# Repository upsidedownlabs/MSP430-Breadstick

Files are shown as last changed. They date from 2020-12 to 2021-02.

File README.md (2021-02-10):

# MSP430 Breadstick

 

Upside Down Labs MSP430 Breadstick is a development board for ultra low power MSP430G2553 MCU from Texas Instruments. 

## Variant: Cheese Dip
Cheese Dip variant of MSP430 Breadstick comes with CH340C USB to UART bridge.

| Front |  Back |
| :---: | :---: |
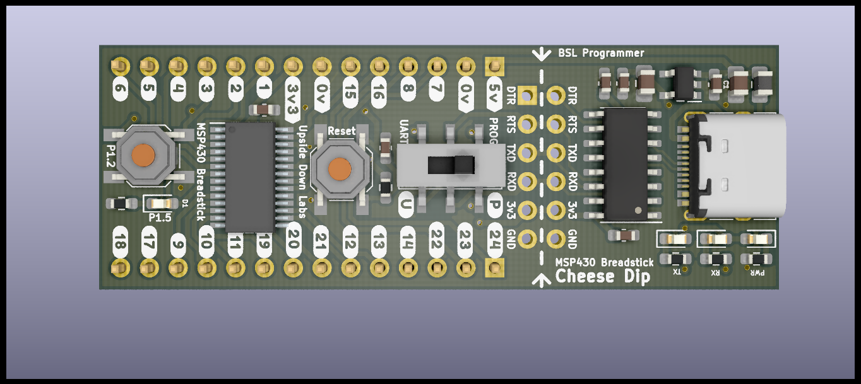
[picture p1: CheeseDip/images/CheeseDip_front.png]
Upside Down Labs MSP430 Breadstick front
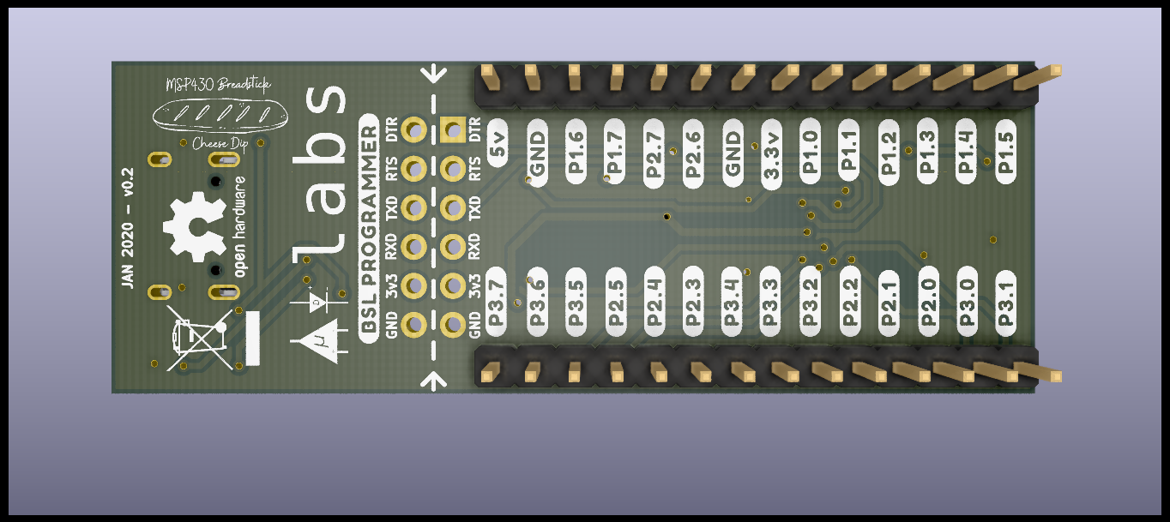
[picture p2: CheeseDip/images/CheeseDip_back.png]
Upside Down Labs MSP430 Breadstick back
|   |  |

|Pinout|
| :--: |
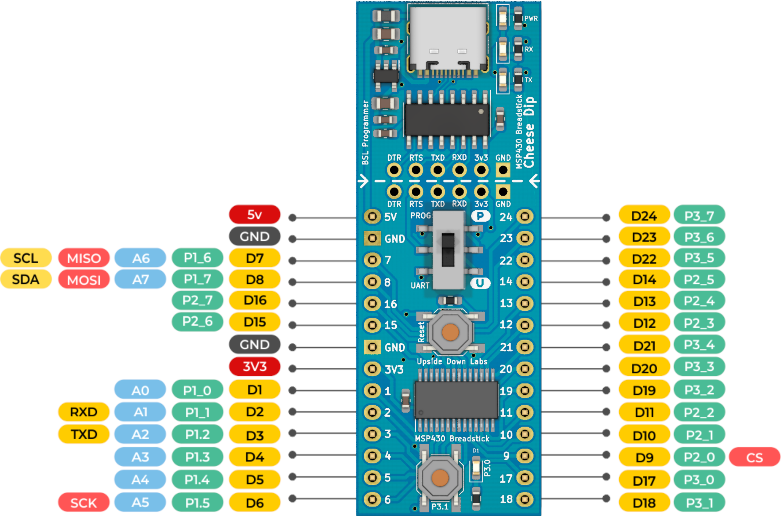
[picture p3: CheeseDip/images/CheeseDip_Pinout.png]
||

| Dimensions |  Schematic |
| :---: | :---: |
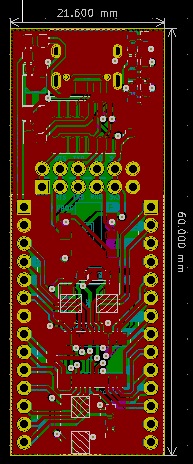
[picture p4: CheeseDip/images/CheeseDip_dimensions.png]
Upside Down Labs MSP430 Breadstick dimensions
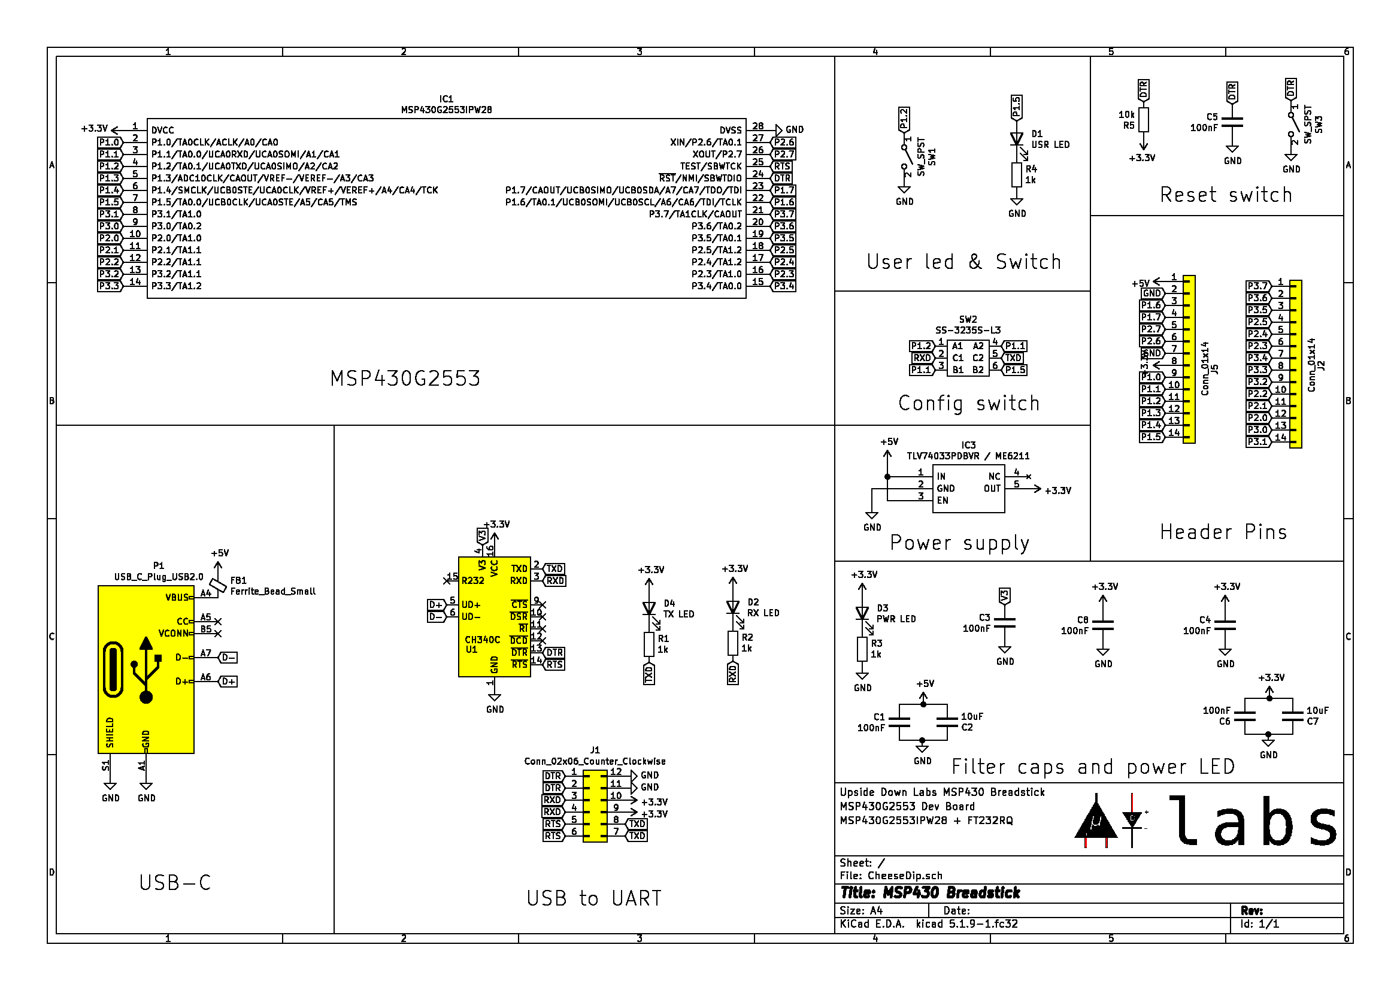
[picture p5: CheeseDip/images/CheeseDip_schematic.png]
Upside Down Labs MSP430 Breadstick schematic
| 60.00 x 21.60 mm  |  |

## Variant: Apple Sauce
Apple Sauce variant of MSP430 Breadstick comes with FT232RQ USB to UART bridge.

| Front |  Back |
| :---: | :---: |
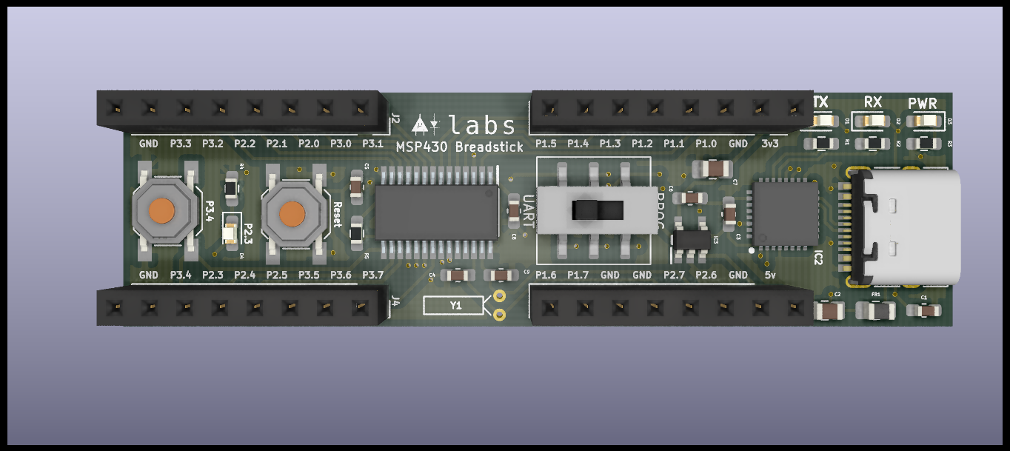
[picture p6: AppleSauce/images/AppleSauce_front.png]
Upside Down Labs MSP430 Breadstick front
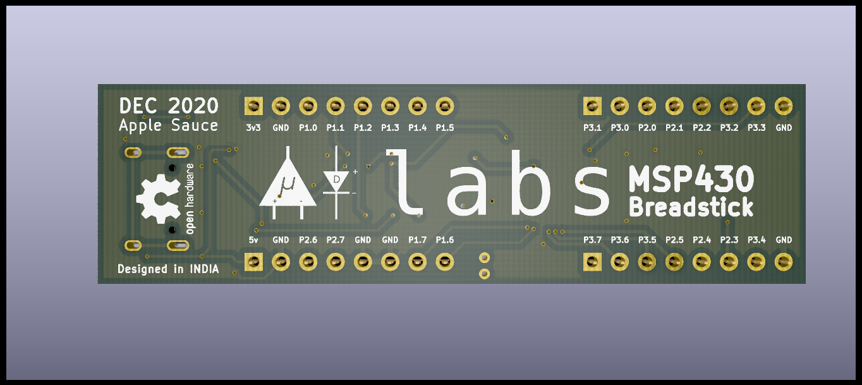
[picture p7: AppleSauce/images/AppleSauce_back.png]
Upside Down Labs MSP430 Breadstick back
|   |  |

| Dimensions |  Schematic |
| :---: | :---: |
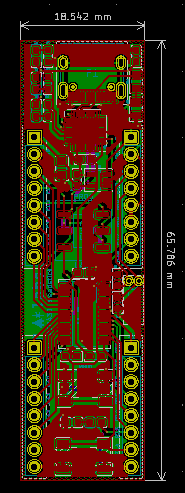
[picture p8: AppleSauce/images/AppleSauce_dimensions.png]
Upside Down Labs MSP430 Breadstick dimensions
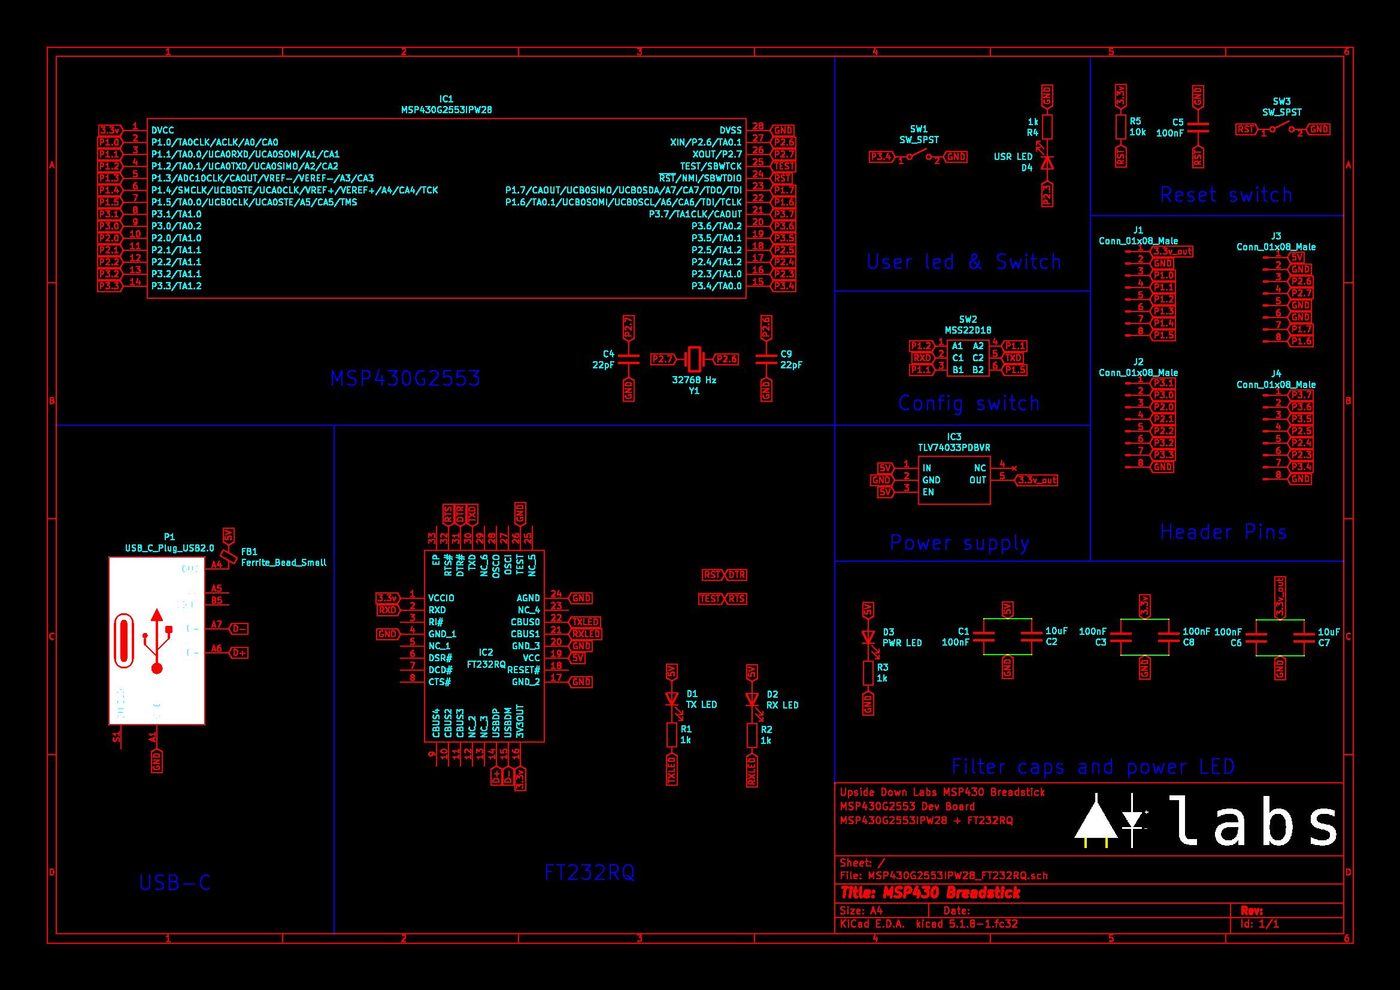
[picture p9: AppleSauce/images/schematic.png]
Upside Down Labs MSP430 Breadstick schematic
| 65.786 x 18.542 mm  |  |

## License

#### Hardware
CERN Open Hardware License Version 2 - Strongly Reciprocal ([CERN-OHL-S-2.0](https://spdx.org/licenses/CERN-OHL-S-2.0.html)).

#### Software
MIT open source [license](http://opensource.org/licenses/MIT).

#### Documentation:
<br />This work is licensed under a <a rel="license" href="http://creativecommons.org/licenses/by/4.0/">Creative Commons Attribution 4.0 International License</a>.

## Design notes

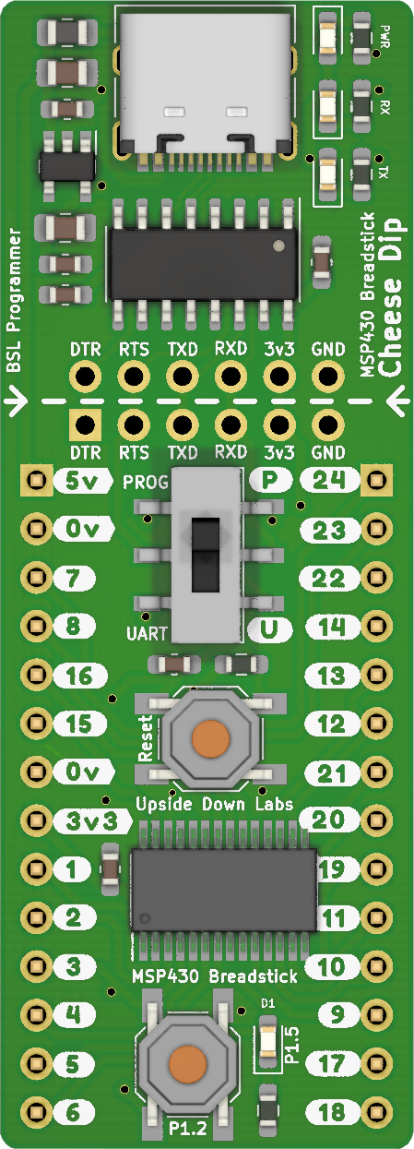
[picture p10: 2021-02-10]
CheeseDip/images/CheeseDip_Dark_Green.png

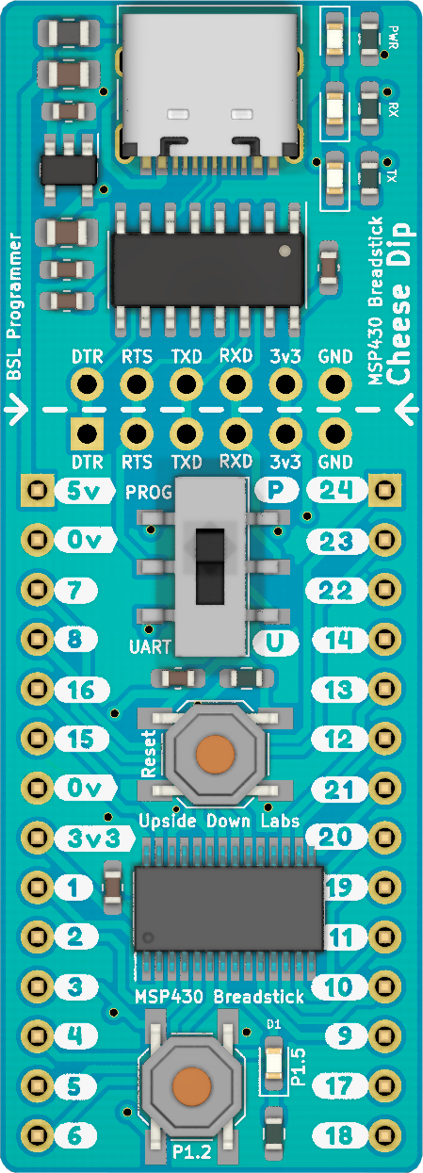
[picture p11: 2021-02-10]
CheeseDip/images/CheeseDip_SeaBlue.png

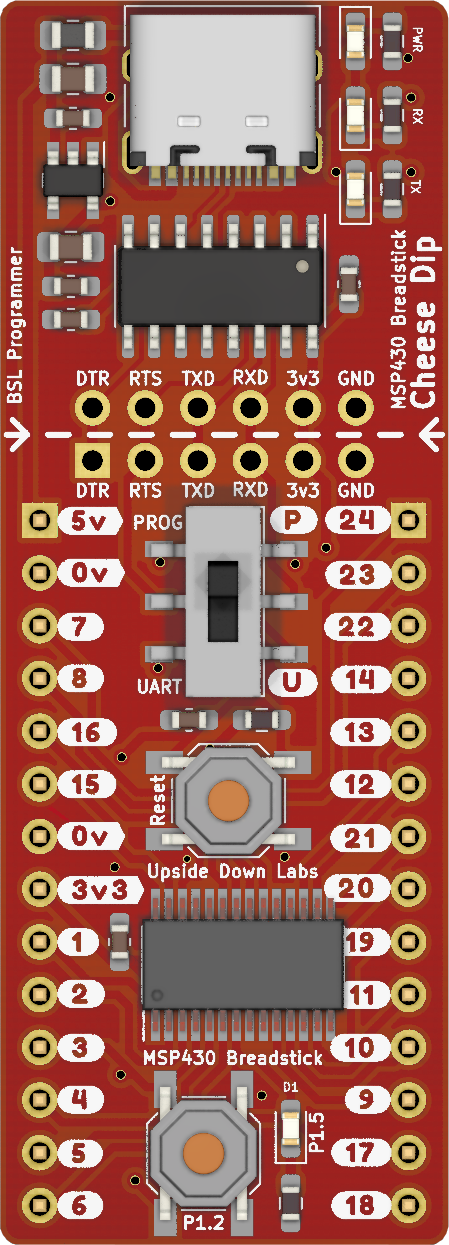
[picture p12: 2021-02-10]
CheeseDip/images/CheeseDip_Brown.png

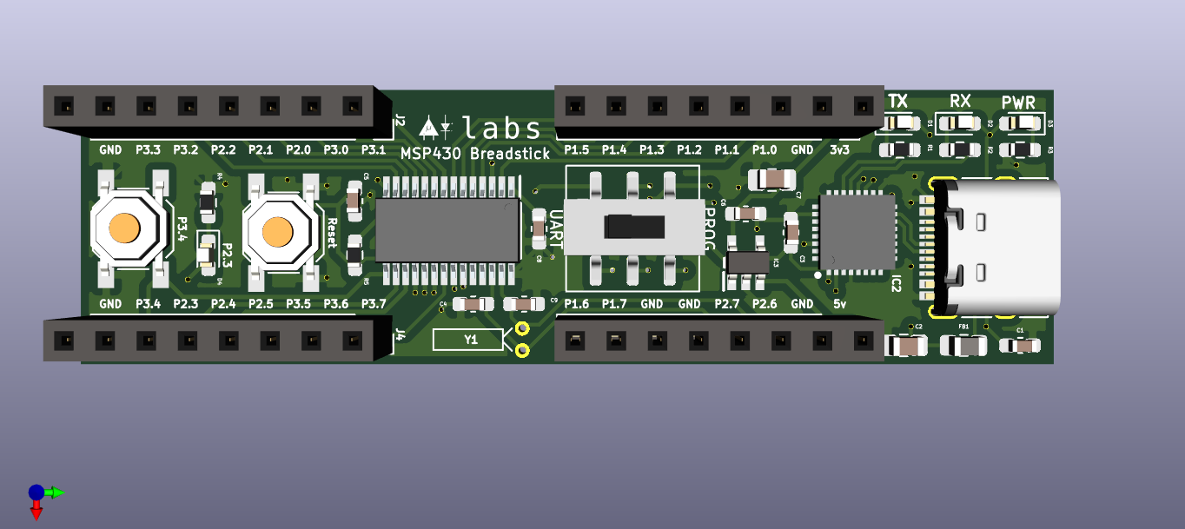
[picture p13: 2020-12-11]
AppleSauce/images/NRT_AppleSauce_front.png

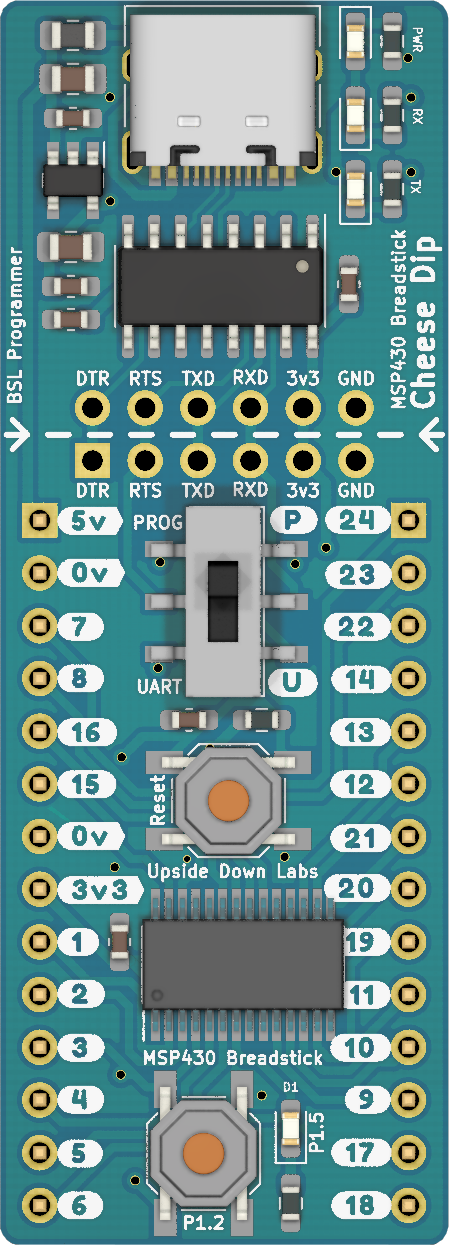
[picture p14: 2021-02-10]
CheeseDip/images/CheeseDip_Deep_Blue.png

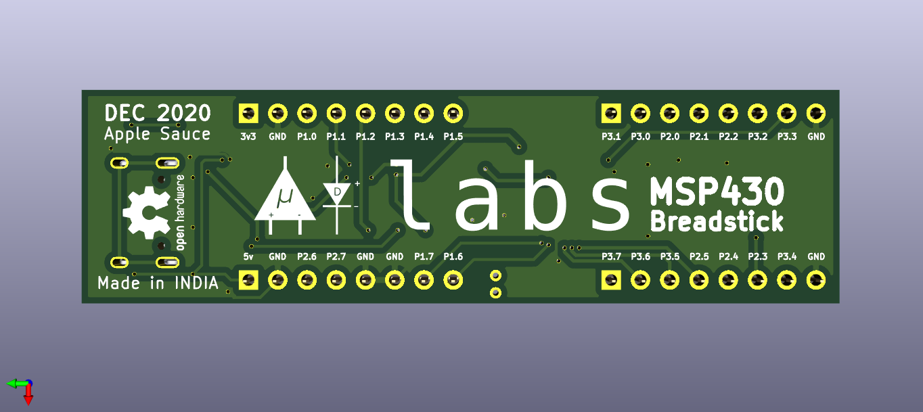
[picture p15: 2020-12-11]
AppleSauce/images/NRT_AppleSauce_back.png

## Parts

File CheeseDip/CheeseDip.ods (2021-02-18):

Ref | Qnty | Value | Cmp name | Footprint | Description | Vendor | LCSC
C1, C3, C4, C5, C6, C8, | 6 | 100nF | C | Capacitor_SMD:C_0603_1608Metric_Pad1.08x0.95mm_HandSolder | Unpolarized capacitor
C2, C7, | 2 | 10uF | C | Capacitor_SMD:C_0805_2012Metric_Pad1.18x1.45mm_HandSolder | Unpolarized capacitor
D1, | 1 | USR LED | LED | LED_SMD:LED_0603_1608Metric_Pad1.05x0.95mm_HandSolder | Light emitting diode
D2, | 1 | RX LED | LED | LED_SMD:LED_0603_1608Metric_Pad1.05x0.95mm_HandSolder | Light emitting diode
D3, | 1 | PWR LED | LED | LED_SMD:LED_0603_1608Metric_Pad1.05x0.95mm_HandSolder | Light emitting diode
D4, | 1 | TX LED | LED | LED_SMD:LED_0603_1608Metric_Pad1.05x0.95mm_HandSolder | Light emitting diode
FB1, | 1 | Ferrite_Bead_Small | Ferrite_Bead_Small | Inductor_SMD:L_0805_2012Metric_Pad1.15x1.40mm_HandSolder | Ferrite bead, small symbol
IC1, | 1 | MSP430G2553IPW28 | MSP430G2553IPW28 | udlabs:MSP430G2553IPW28 | Mixed Signal MCU MSP430 16K Flash TSSOP Texas Instruments MSP430G2553IPW28, 16bit MSP430 Microcontroller, 16MHz, 16 kB Flash, 28-Pin TSSOP | Texas Instruments | C13622
IC3, | 1 | ME6211 | ME6211 | udlabs:ME6211 | LDO Voltage Regulators |  | C82942
P1, | 1 | USB_C_Plug_USB2.0 | USB_C_Plug_USB2.0 | Connector_USB:USB_C_Receptacle_HRO_TYPE-C-31-M-12 | USB 2.0-only Type-C Plug connector |  | C720629
R1, R2, R3, R4, | 4 | 1k | R | Resistor_SMD:R_0603_1608Metric_Pad0.98x0.95mm_HandSolder | Resistor
R5, | 1 | 10k | R | Resistor_SMD:R_0603_1608Metric_Pad0.98x0.95mm_HandSolder | Resistor
SW1, SW3, | 2 | SW_SPST | SW_SPST | Button_Switch_SMD:SW_SPST_SKQG_WithStem | Single Pole Single Throw (SPST) switch |  | C318884
SW2, | 1 | SS-3235S-L3 | SS-3235S-L3 | udlabs:SS-3235S-L3 |  |  | C381098
U1, | 1 | CH340C | CH340C | Package_SO:SOIC-16_3.9x9.9mm_P1.27mm | USB serial converter, UART, SOIC-16 |  | C84681
Component Count: | 28

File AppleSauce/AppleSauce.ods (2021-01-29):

Source: | MSP430_Breadstick/MSP430G2553IPW28_FT232RQ/MSP430G2553IPW28_FT232RQ.sch
Date: | Wed 13 Jan 2021 12:40:15 PM IST
Tool: | Eeschema 5.1.9-1.fc32
Generator: | /usr/share/kicad/plugins/bom_csv_grouped_by_value_with_fp.py
Component Count: | 31
Ref | Qnty | Value | Cmp name | Footprint | Description | Vendor
C1, C3, C5, C6, C8, | 5 | 100nF | C | Capacitor_SMD:C_0603_1608Metric_Pad1.08x0.95mm_HandSolder | Unpolarized capacitor
C2, C7, | 2 | 10uF | C | Capacitor_SMD:C_0805_2012Metric_Pad1.18x1.45mm_HandSolder | Unpolarized capacitor
C4, C9, | 2 | 22pF | C | Capacitor_SMD:C_0603_1608Metric_Pad1.08x0.95mm_HandSolder | Unpolarized capacitor
D1, | 1 | TX LED | LED | LED_SMD:LED_0603_1608Metric_Pad1.05x0.95mm_HandSolder | Light emitting diode
D2, | 1 | RX LED | LED | LED_SMD:LED_0603_1608Metric_Pad1.05x0.95mm_HandSolder | Light emitting diode
D3, | 1 | PWR LED | LED | LED_SMD:LED_0603_1608Metric_Pad1.05x0.95mm_HandSolder | Light emitting diode
D4, | 1 | USR LED | LED | LED_SMD:LED_0603_1608Metric_Pad1.05x0.95mm_HandSolder | Light emitting diode
FB1, | 1 | Ferrite_Bead_Small | Ferrite_Bead_Small | Inductor_SMD:L_0805_2012Metric_Pad1.15x1.40mm_HandSolder | Ferrite bead, small symbol
IC1, | 1 | MSP430G2553IPW28 | MSP430G2553IPW28 | udlabs:MSP430G2553IPW28 | Mixed Signal MCU MSP430 16K Flash TSSOP Texas Instruments MSP430G2553IPW28, 16bit MSP430 Microcontroller, 16MHz, 16 kB Flash, 28-Pin TSSOP
IC2, | 1 | FT232RQ | FT232RQ | udlabs:FT232RQ | USB Interface IC USB to Serial UART Enhanced IC QFN-32
IC3, | 1 | TLV74033PDBVR | TLV74033PDBVR | udlabs:TLV74033PDBVR | LDO Voltage Regulators
J1, J2, J3, J4, | 4 | Conn_01x08_Male | Conn_01x08_Male | Connector_PinSocket_2.54mm:PinSocket_1x08_P2.54mm_Vertical | Generic connector, single row, 01x08, script generated (kicad-library-utils/schlib/autogen/connector/)
P1, | 1 | USB_C_Plug_USB2.0 | USB_C_Plug_USB2.0 | Connector_USB:USB_C_Receptacle_HRO_TYPE-C-31-M-12 | USB 2.0-only Type-C Plug connector
R1, R2, R3, R4, | 4 | 1k | R | Resistor_SMD:R_0603_1608Metric_Pad0.98x0.95mm_HandSolder | Resistor
R5, | 1 | 10k | R | Resistor_SMD:R_0603_1608Metric_Pad0.98x0.95mm_HandSolder | Resistor
SW1, SW3, | 2 | SW_SPST | SW_SPST | Button_Switch_SMD:SW_SPST_SKQG_WithStem | Single Pole Single Throw (SPST) switch
SW2, | 1 | MSS22D18 | MSS22D18 | udlabs:MSS22D18
Y1, | 1 | 32768 Hz | Crystal | Crystal:Crystal_DS10_D1.0mm_L4.3mm_Horizontal | Two pin crystal

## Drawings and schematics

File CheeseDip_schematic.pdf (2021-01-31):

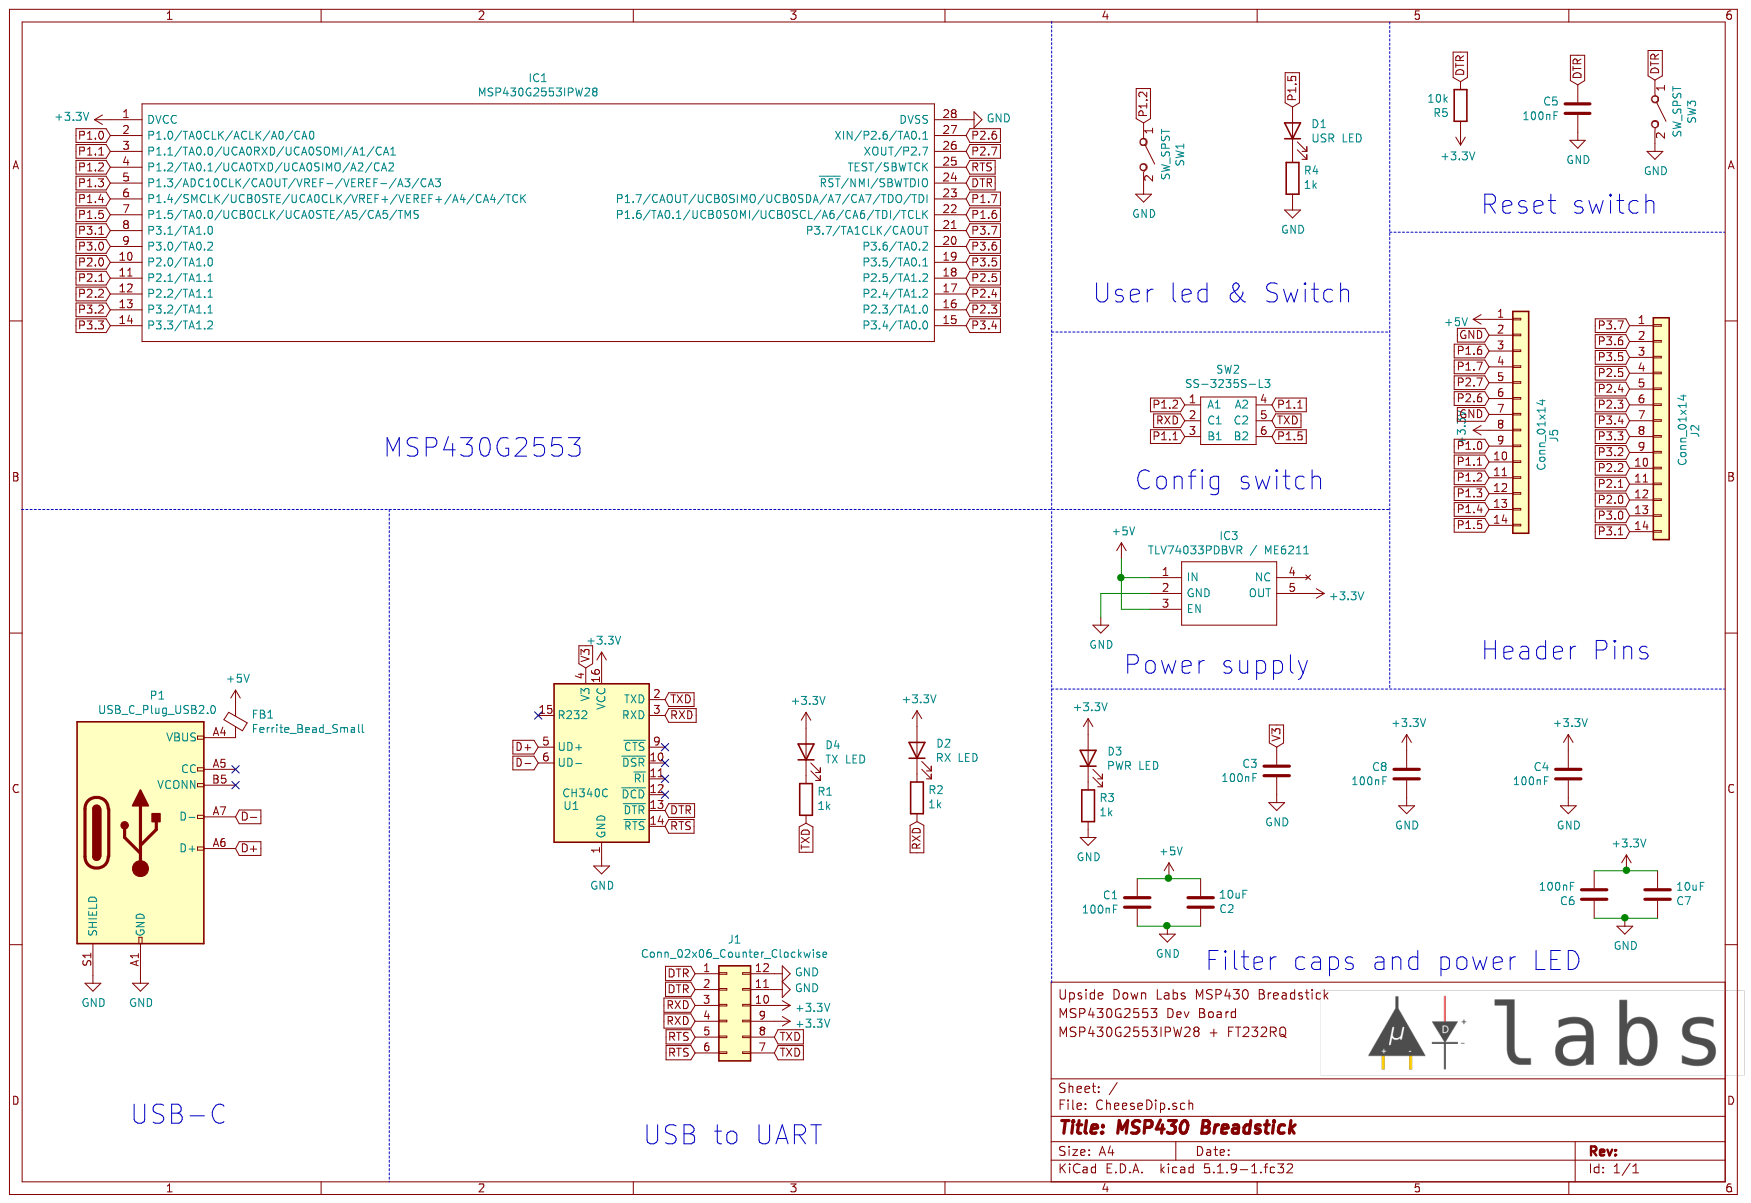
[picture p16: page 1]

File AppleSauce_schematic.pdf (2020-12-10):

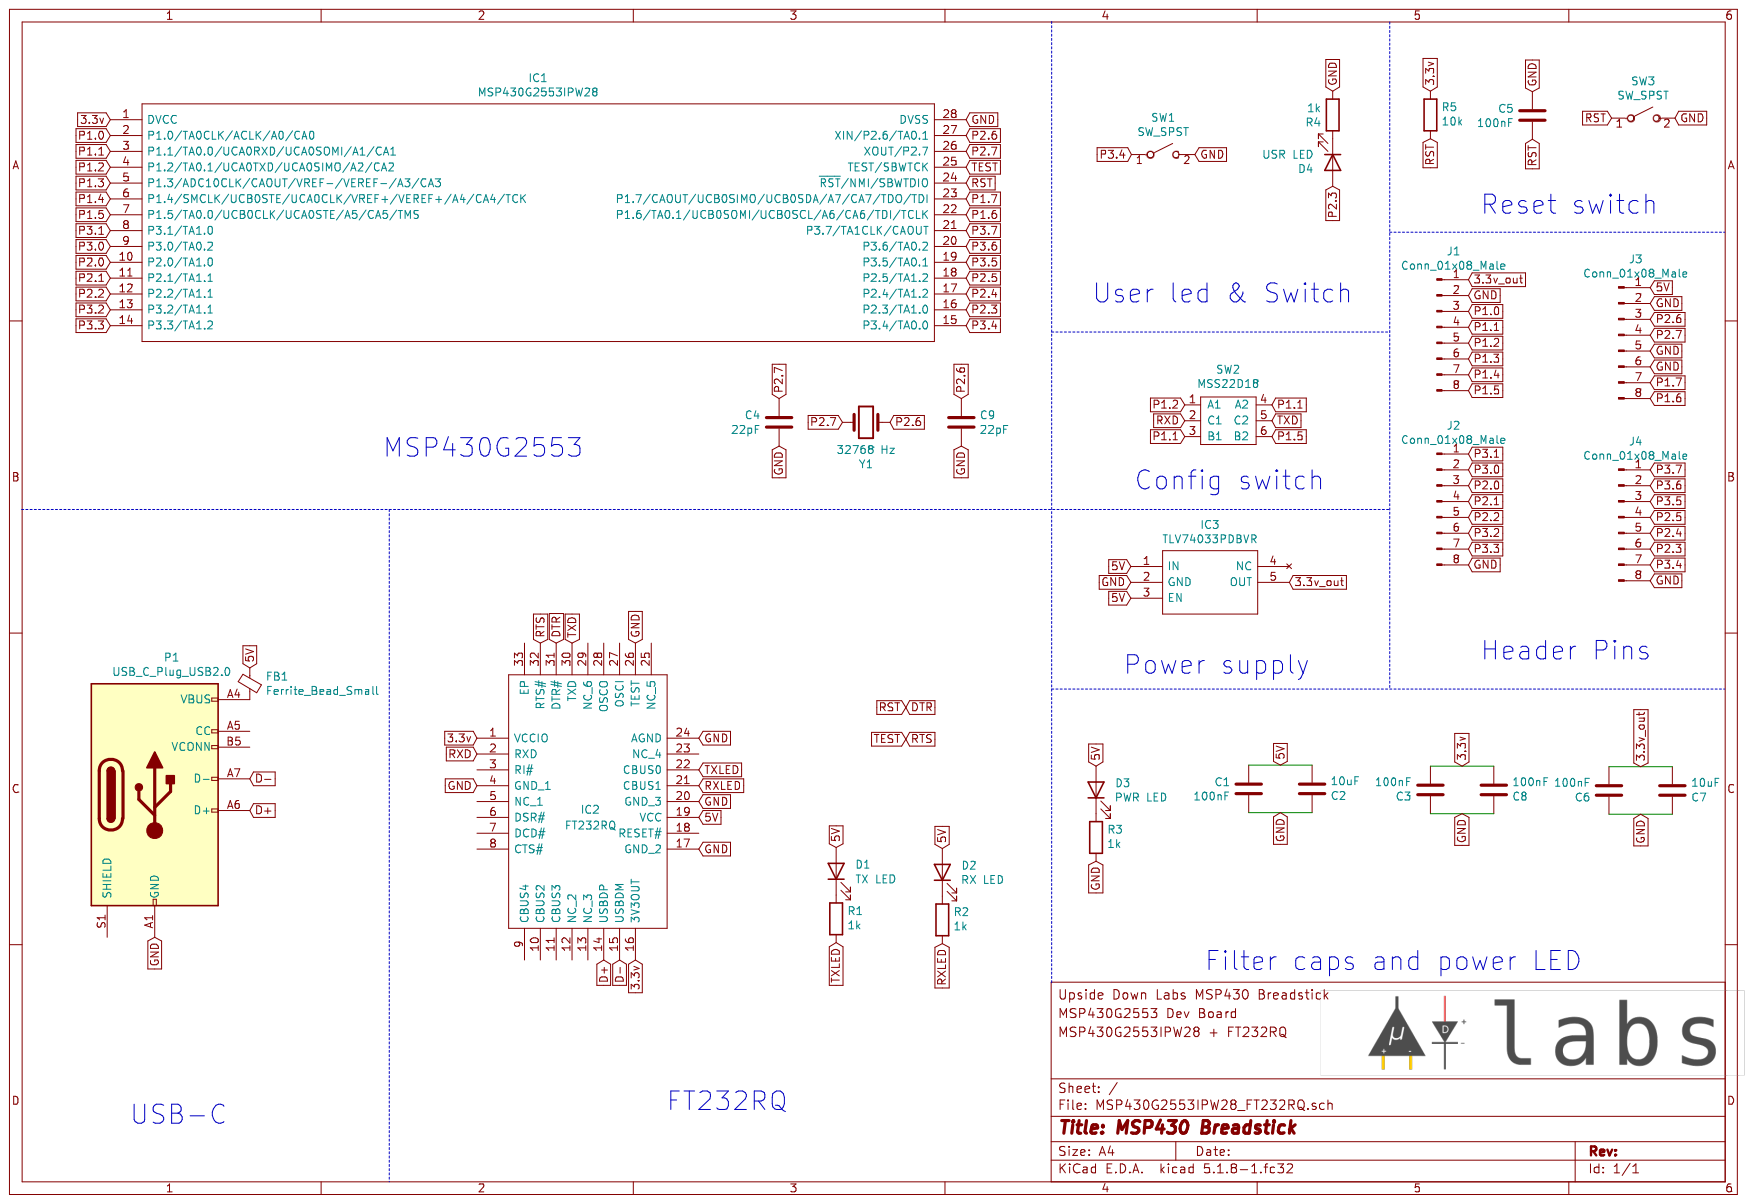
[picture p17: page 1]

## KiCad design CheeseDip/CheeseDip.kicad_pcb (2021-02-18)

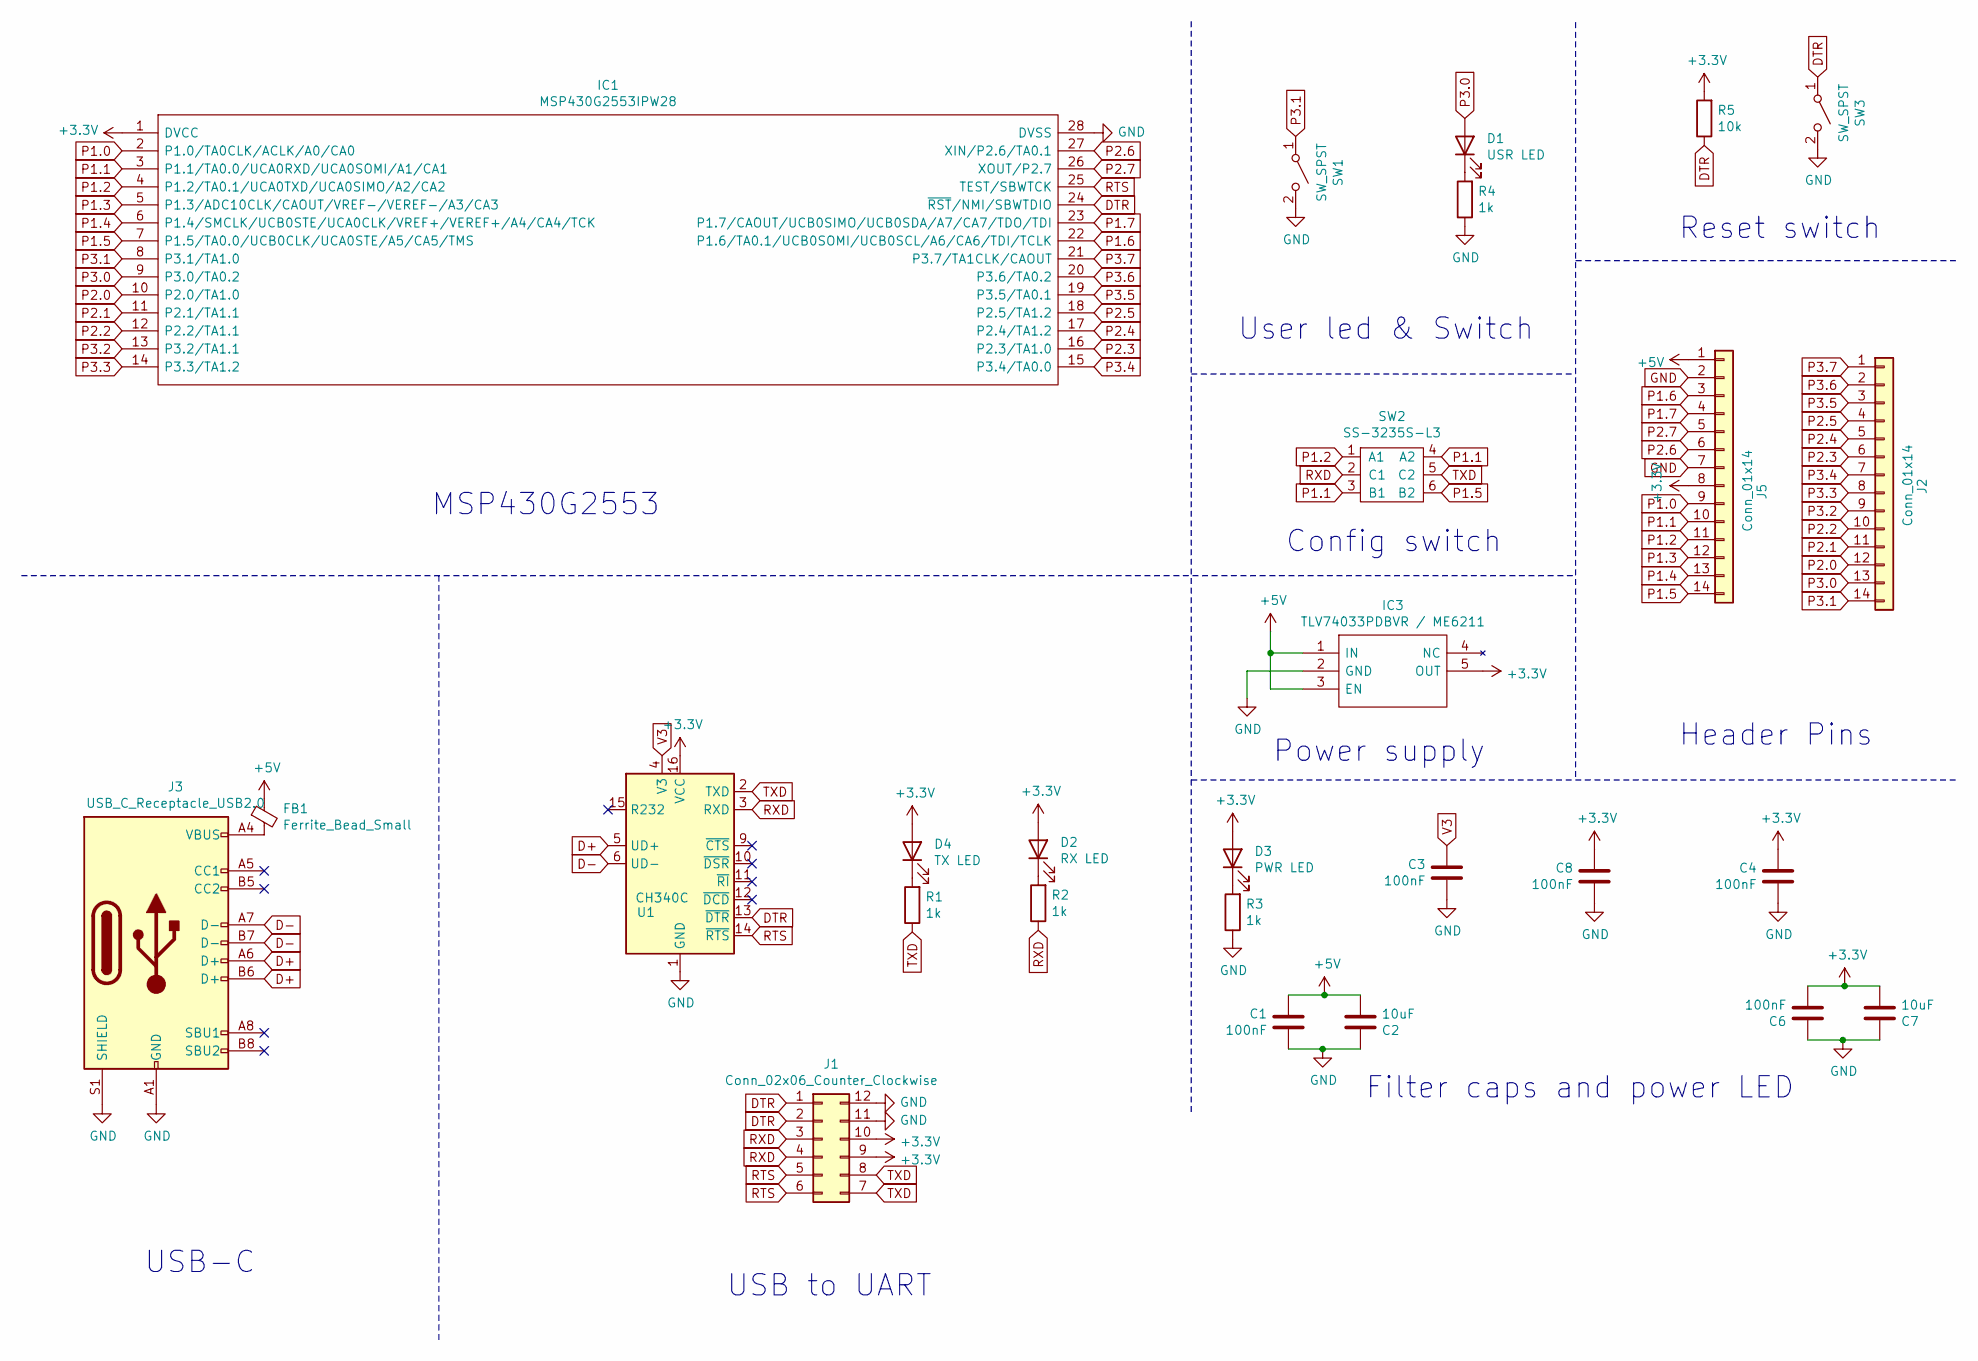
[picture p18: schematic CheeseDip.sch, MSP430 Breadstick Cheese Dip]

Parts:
C1, C3, C4, C6, C8: 100nF; C_0603_1608Metric_Pad1.08x0.95mm_HandSolder
C2, C7: 10uF; C_0805_2012Metric_Pad1.18x1.45mm_HandSolder
D1: USR LED; LED_0603_1608Metric_Pad1.05x0.95mm_HandSolder
D2: RX LED; LED_0603_1608Metric_Pad1.05x0.95mm_HandSolder
D3: PWR LED; LED_0603_1608Metric_Pad1.05x0.95mm_HandSolder
D4: TX LED; LED_0603_1608Metric_Pad1.05x0.95mm_HandSolder
FB1: Ferrite_Bead_Small; L_0805_2012Metric_Pad1.15x1.40mm_HandSolder
IC1: MSP430G2553IPW28; Manufacturer_Part_Number MSP430G2553IPW28; Mouser Part Number 595-MSP430G2553IPW28
IC3: TLV74033PDBVR / ME6211; TLV74033PDBVR; Manufacturer_Part_Number TLV74033PDBVR
J1: Conn_02x06_Counter_Clockwise; progMSP
J2, J5: Conn_01x14; PinHeader_1x14_P2.54mm_Vertical
J3: USB_C_Receptacle_USB2.0; USB_C_Receptacle_HRO_TYPE-C-31-M-12
R1, R2, R3, R4: 1k; R_0603_1608Metric_Pad0.98x0.95mm_HandSolder
R5: 10k; R_0603_1608Metric_Pad0.98x0.95mm_HandSolder
SW1, SW3: SW_SPST; SW_SPST_SKQG_WithStem
SW2: SS-3235S-L3
U1: CH340C; SOIC-16_3.9x9.9mm_P1.27mm

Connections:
+3V3: C4.1, C6.2, C7.2, C8.1, D2.2 (A), D3.2 (A), D4.2 (A), IC1.1 (DVCC), IC3.5 (OUT), J1.9, J1.10, J5.8, R5.2, U1.16 (VCC)
+5V: C1.1, C2.2, FB1.1, IC3.1 (IN), IC3.3 (EN), J5.1
D+: J3.A6 (D+), J3.B6 (D+), U1.5 (UD+)
D-: J3.A7 (D-), J3.B7 (D-), U1.6 (UD-)
DTR: IC1.24 (~RST~/NMI/SBWTDIO), J1.1, J1.2, R5.1, SW3.1 (A), U1.13 (~DTR)
GND: C1.2, C2.1, C3.2, C4.2, C6.1, C7.1, C8.2, IC1.28 (DVSS), IC3.2 (GND), J1.11, J1.12, J3.A1 (GND), J3.A12 (GND), J3.B1 (GND), J3.B12 (GND), J3.S1 (SHIELD), J5.2, J5.7, R3.1, R4.1, SW1.2 (B), SW3.2 (B), U1.1 (GND)
unnamed: D1.1 (K), R4.2
unnamed: D2.1 (K), R2.2
unnamed: D3.1 (K), R3.2
unnamed: D4.1 (K), R1.2
unnamed: FB1.2, J3.A4 (VBUS), J3.A9 (VBUS), J3.B4 (VBUS), J3.B9 (VBUS)
P1.0: IC1.2 (P1.0/TA0CLK/ACLK/A0/CA0), J5.9
P1.1: IC1.3 (P1.1/TA0.0/UCA0RXD/UCA0SOMI/A1/CA1), J5.10, SW2.3 (B1), SW2.4 (A2)
P1.2: IC1.4 (P1.2/TA0.1/UCA0TXD/UCA0SIMO/A2/CA2), J5.11, SW2.1 (A1)
P1.3: IC1.5 (P1.3/ADC10CLK/CAOUT/VREF-/VEREF-/A3/CA3), J5.12
P1.4: IC1.6 (P1.4/SMCLK/UCB0STE/UCA0CLK/VREF+/VEREF+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), J5.13
P1.5: IC1.7 (P1.5/TA0.0/UCB0CLK/UCA0STE/A5/CA5/TMS), J5.14, SW2.6 (B2)
P1.6: IC1.22 (P1.6/TA0.1/UCB0SOMI/UCB0SCL/A6/CA6/TDI/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), J5.3
P1.7: IC1.23 (P1.7/CAOUT/UCB0SIMO/UCB0SDA/A7/CA7/TDO/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), J5.4
P2.0: IC1.10 (P2.0/TA1.0), J2.12
P2.1: IC1.11 (P2.1/TA1.1), J2.11
P2.2: IC1.12 (P2.2/TA1.1), J2.10
P2.3: IC1.16 (P2.3/TA1.0), J2.6
P2.4: IC1.17 (P2.4/TA1.2), J2.5
P2.5: IC1.18 (P2.5/TA1.2), J2.4
P2.6: IC1.27 (XIN/P2.6/TA0.1), J5.6
P2.7: IC1.26 (XOUT/P2.7), J5.5
P3.0: D1.2 (A), IC1.9 (P3.0/TA0.2), J2.13
P3.1: IC1.8 (P3.1/TA1.0), J2.14, SW1.1 (A)
P3.2: IC1.13 (P3.2/TA1.1), J2.9
P3.3: IC1.14 (P3.3/TA1.2), J2.8
P3.4: IC1.15 (P3.4/TA0.0), J2.7
P3.5: IC1.19 (P3.5/TA0.1), J2.3
P3.6: IC1.20 (P3.6/TA0.2), J2.2
P3.7: IC1.21 (P3.7/TA1CLK/CAOUT), J2.1
RTS: IC1.25 (TEST/SBWTCK), J1.5, J1.6, U1.14 (~RTS)
RXD: J1.3, J1.4, R2.1, SW2.2 (C1), U1.3 (RXD)
TXD: J1.7, J1.8, R1.1, SW2.5 (C2), U1.2 (TXD)
V3: C3.1, U1.4 (V3)

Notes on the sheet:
MSP430G2553
USB to UART
USB-C
Power supply
Header Pins
Config switch
User led & Switch
Reset switch
Filter caps and power LED

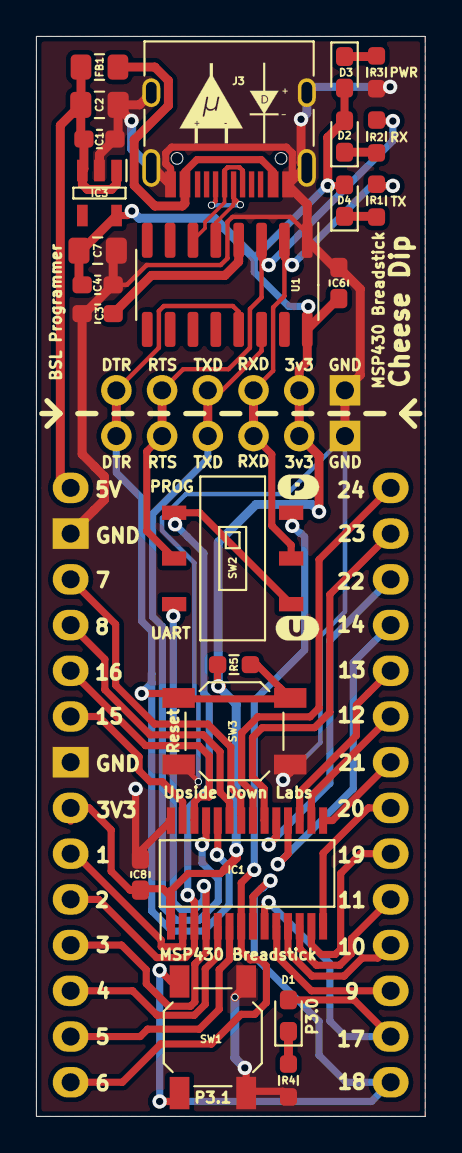
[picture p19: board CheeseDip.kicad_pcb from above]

Board: 2 copper layers, 21.6 x 60.0 mm, 27 parts (0 on the bottom side), 39 nets.

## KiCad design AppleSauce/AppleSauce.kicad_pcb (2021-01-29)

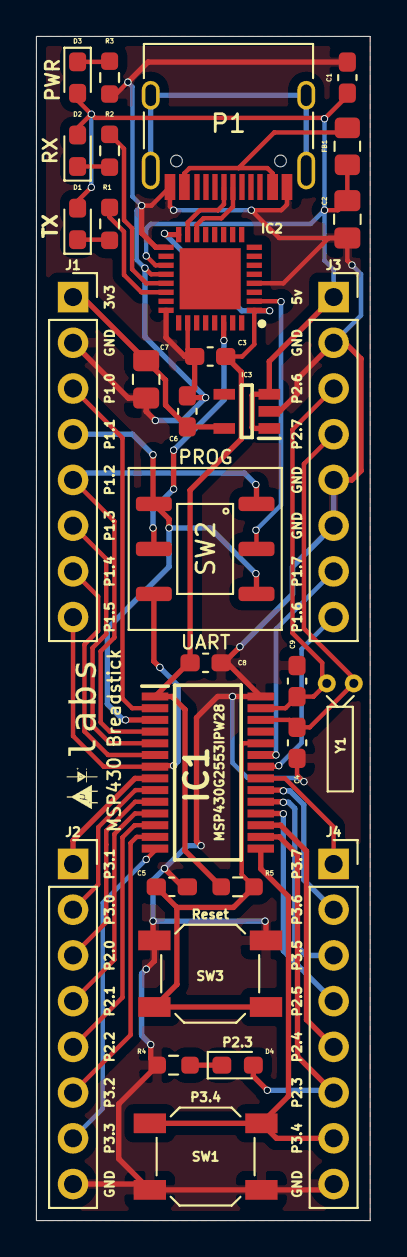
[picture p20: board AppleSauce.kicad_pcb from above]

Board: 2 copper layers, 18.5 x 65.8 mm, 31 parts (0 on the bottom side), 40 nets.

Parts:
C1, C3, C5, C6, C8: 100nF; C_0603_1608Metric_Pad1.08x0.95mm_HandSolder
C2, C7: 10uF; C_0805_2012Metric_Pad1.18x1.45mm_HandSolder
C4, C9: 22pF; C_0603_1608Metric_Pad1.08x0.95mm_HandSolder
D1: TX LED; LED_0603_1608Metric_Pad1.05x0.95mm_HandSolder
D2: RX LED; LED_0603_1608Metric_Pad1.05x0.95mm_HandSolder
D3: PWR LED; LED_0603_1608Metric_Pad1.05x0.95mm_HandSolder
D4: USR LED; LED_0603_1608Metric_Pad1.05x0.95mm_HandSolder
FB1: Ferrite_Bead_Small; L_0805_2012Metric_Pad1.15x1.40mm_HandSolder
IC1: MSP430G2553IPW28
IC2: FT232RQ
IC3: TLV74033PDBVR
J1, J2, J3, J4: Conn_01x08_Male; PinSocket_1x08_P2.54mm_Vertical
P1: USB_C_Plug_USB2.0; USB_C_Receptacle_HRO_TYPE-C-31-M-12
R1, R2, R3, R4: 1k; R_0603_1608Metric_Pad0.98x0.95mm_HandSolder
R5: 10k; R_0603_1608Metric_Pad0.98x0.95mm_HandSolder
SW1, SW3: SW_SPST; SW_SPST_SKQG_WithStem
SW2: MSS22D18
Y1: 32768 Hz; Crystal_DS10_D1.0mm_L4.3mm_Horizontal

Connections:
3.3v: C3.2, C8.2, IC1.1, IC2.1, IC2.16, R5.2
3.3v_out: C6.2, C7.2, IC3.5, J1.1
5V: C1.1, C2.2, D1.2, D2.2, D3.2, FB1.1, IC2.19, IC3.1, IC3.3, J3.1
D+: IC2.14, P1.A6
D-: IC2.15, P1.A7
GND: C1.2, C2.1, C3.1, C4.2, C5.1, C6.1, C7.1, C8.1, C9.2, IC1.28, IC2.4, IC2.17, IC2.20, IC2.24, IC2.26, IC3.2, J1.2, J2.8, J3.2, J3.5, J3.6, J4.8, P1.A1, P1.A12, P1.B1, P1.B12, R3.1, R4.1, SW1.2, SW3.2
unnamed: D1.1, R1.2
unnamed: D2.1, R2.2
unnamed: D3.1, R3.2
unnamed: D4.1, R4.2
unnamed: FB1.2, P1.A4, P1.A9, P1.B4, P1.B9
P1.0: IC1.2, J1.3
P1.1: IC1.3, J1.4, SW2.3, SW2.4
P1.2: IC1.4, J1.5, SW2.1
P1.3: IC1.5, J1.6
P1.4: IC1.6, J1.7
P1.5: IC1.7, J1.8, SW2.6
P1.6: IC1.22, J3.8
P1.7: IC1.23, J3.7
P2.0: IC1.10, J2.3
P2.1: IC1.11, J2.4
P2.2: IC1.12, J2.5
P2.3: D4.2, IC1.16, J4.6
P2.4: IC1.17, J4.5
P2.5: IC1.18, J4.4
P2.6: C9.1, IC1.27, J3.3, Y1.1
P2.7: C4.1, IC1.26, J3.4, Y1.2
P3.0: IC1.9, J2.2
P3.1: IC1.8, J2.1
P3.2: IC1.13, J2.6
P3.3: IC1.14, J2.7
P3.4: IC1.15, J4.7, SW1.1
P3.5: IC1.19, J4.3
P3.6: IC1.20, J4.2
P3.7: IC1.21, J4.1
RST: C5.2, IC1.24, R5.1, SW3.1
RXD: IC2.2, SW2.2
RXLED: IC2.21, R2.1
TXD: IC2.30, SW2.5
TXLED: IC2.22, R1.1

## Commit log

2020-12-10 Add apple sauce to breadstick
    [MSP430G2553IPW28_FT232RQ.kicad_pcb, MSP430G2553IPW28_FT232RQ.sch]
2020-12-11 update project
    add 3d models and create new silkscreen elements.
    [MSP430G2553IPW28_FT232RQ.kicad_pcb]
2020-12-11 update images
    add schematic and update presious images.
2020-12-11 update readme
    New high-contrast schematic image added.
2021-01-20 Added Breadstick KiCAD-Template.
    - Use these files to create shields. It provides you pre designed board outlines and connector.
    [MSP430G2553IPW28_FT232RQ.kicad_pcb, MSP430G2553IPW28_FT232RQ.sch]
2021-01-29 Update Apple Sauce board
    [AppleSauce.kicad_pcb, AppleSauce.ods, AppleSauce.sch]
2021-01-31 add Cheese Dip KiCad files
    These KiCAD files are for Cheese Dip variant of MSP430 Breadstick.
    [CheeseDip.kicad_pcb, CheeseDip.sch]
2021-01-31 add Cheese Dip schematic
2021-02-10 Fix silkscreen
    [CheeseDip.kicad_pcb]
2021-02-18 Update to v0.5
    [CheeseDip-Castellated.kicad_pcb, CheeseDip.kicad_pcb, CheeseDip.ods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]
